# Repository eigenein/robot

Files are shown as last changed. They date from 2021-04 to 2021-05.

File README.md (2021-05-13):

Yes, it's yet another hobby robot, like many of those based on Arduino. So, to make it more fun, it features:

- Raspberry Pi Pico instead of an Arduino board
- My own tiny asynchronous event loop (since [CircuitPython doesn't have one](https://learn.adafruit.com/welcome-to-circuitpython/frequently-asked-questions))
- Custom «asynchronous» BNO055 driver
- Multiple asynchronous tasks running «at the same time»
- Simple REPL over Bluetooth
- Schematics & PCB design included

## Parts

- [Raspberry Pi Pico](https://www.raspberrypi.org/products/raspberry-pi-pico/)
- [Adafruit TB6612 Motor Driver Breakout Board](https://learn.adafruit.com/adafruit-tb6612-h-bridge-dc-stepper-motor-driver-breakout)
- JDY-31 Bluetooth Module
- VL53L1X Distance Sensor Breakout
- BNO055 Absolute Orientation IMU Fusion Breakout
- PS2 Wireless Receiver
- Piezo Buzzer

## Schematics

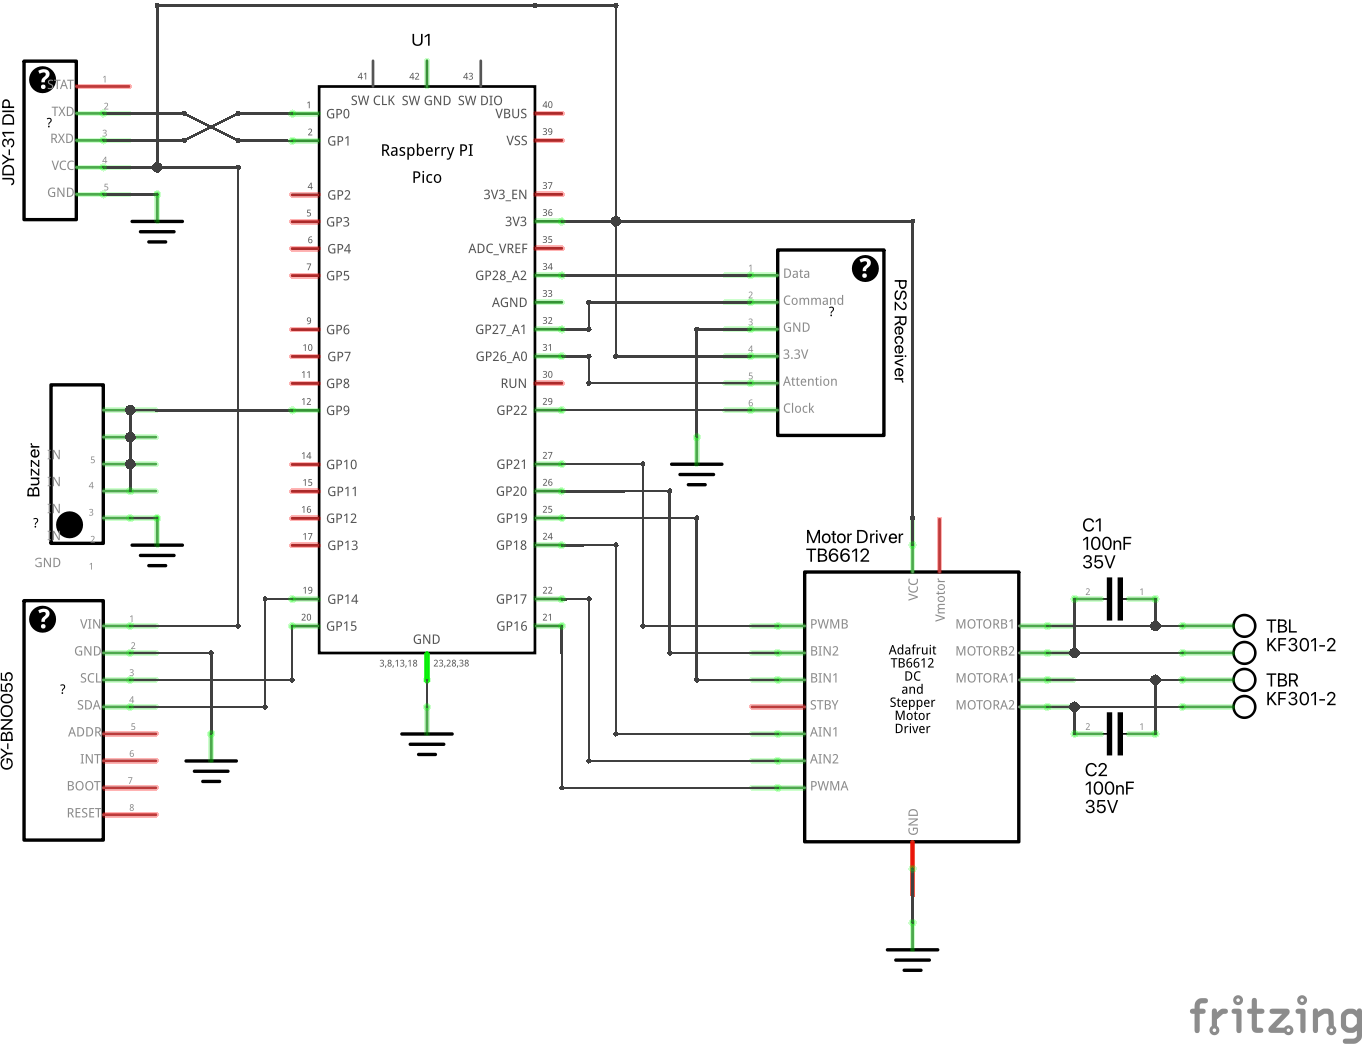
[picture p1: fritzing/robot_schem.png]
Schematics image


## External resources

- [CircuitPython builds](https://adafruit-circuit-python.s3.amazonaws.com/index.html?prefix=bin/raspberry_pi_pico/en_GB/)
- [Pi Pico pinout](https://datasheets.raspberrypi.org/pico/Pico-R3-A4-Pinout.pdf)
- [Material – Color – Dark theme](https://material.io/design/color/dark-theme.html)

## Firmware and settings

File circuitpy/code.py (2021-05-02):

from ulab.numpy import ndarray

from micro_asyncio import event_loop, sleep
from micro_logging import error, info
from peripherals import led, orientation_sensor
from repl import run as run_repl


class Main:
    def __init__(self):
        self._euler = ndarray((0.0, 0.0, 0.0))  # FIXME: make it `None`.

    async def run(self):
        await orientation_sensor.begin()
        event_loop.schedule(
            self._run_telemetry(),
            self._run_orientation_sensor(),
            run_repl(),
        )

    async def _run_telemetry(self):
        """Continuously print telemetry to the console."""
        while True:
            info(" | ".join((
                f"Orientation: {self._euler[0]}",
            )))
            led.value = not led.value
            await sleep(0.5)

    async def _run_orientation_sensor(self):
        """Continuously read the orientation sensor."""
        while True:
            await sleep(0.01)  # fusion output rate is 100Hz
            try:
                self._euler = await orientation_sensor.get_euler()
            except OSError as e:
                error(f"orientation sensor error: {e}")


if __name__ == "__main__":
    info("Starting…")
    event_loop.schedule(Main().run()).run_until_complete()

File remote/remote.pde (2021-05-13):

final color COLOR_BACKGROUND = #121212;
final color COLOR_WHITE = #FFFFFF;

final float TEXT_ALPHA_HIGH_EMPHASIS = 221.85;
final float TEXT_ALPHA_MEDIUM_EMPHASIS = 153;
final float TEXT_ALPHA_DISABLED = 96.9;

final float FONT_SIZE_BODY_1 = 16;
final float FONT_SIZE_BODY_2 = 14;
final float FONT_SIZE_CAPTION = 12;

PFont roboto;

void setup() {
  size(640, 480);
  surface.setTitle("Robot Remote");
  
  smooth();
  noStroke();
  
  roboto = createFont("Roboto", 16, false);
  textFont(roboto);
}

void draw() {
  background(COLOR_BACKGROUND);
  textSize(FONT_SIZE_BODY_1);
  fill(COLOR_WHITE, TEXT_ALPHA_HIGH_EMPHASIS);
  text("Hello, world!", 20, 20);
}

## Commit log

2021-02-24 🎉 Initial commit
    [robot.fz]
2021-02-24 🚧 Add draft schematics
    [robot.fz, robot.fzz]
2021-02-24 🚧 PCB in progress
    [robot.fzz]
2021-02-24 🐛 Fix incorrect connections
    [robot.fzz]
2021-02-24 🐛 Fix Nano Every internal connections
    [robot.fzz]
2021-02-24 🚧 Add Gerber
    [robot_contour.gm1, robot_copperBottom.gbl, robot_copperTop.gtl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]
2021-02-24 🎨 Improve motor driver routing
    [robot.fzz]
2021-02-24 🎨 Improve the component locations
    [robot.fzz]
2021-02-25 🎨 Improve PCB layout
    [robot.fzz]
2021-02-25 ✨ Add PS2 receiver
    [robot.fzz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]
2021-02-25 ✨ Add planned features
2021-02-26 ✨ Add JDY-31 Bluetooth module
    [robot.fzz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]
2021-02-26 ✏️ Update the schematics
2021-02-26 ⚗ Playing with HMC5883L magnetic field sensor
    [robot.fzz]
2021-02-27 ✨ Implement basic compass
2021-02-27 🐛 Fix the capacitors packaging
    [robot.fzz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]
2021-02-27 ✨ Read wheel rotary encoders
2021-02-27 🐛 Fix the buzzer pinout
    [robot.fzz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]
2021-02-27 🚧 Add individual interrupt handlers for both wheels
2021-02-28 🐛 Fix the silk layer, add spare mounting holes
    [robot.fzz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]
2021-02-28 ✨ Implement the draft console functionality
2021-02-28 🚧 Control motors
2021-02-28 ✨ Add extension ports
    [robot.fzz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]
2021-02-28 🐛 Fix README
2021-03-01 💥 Replace HMC5883L with GY-BNO055
    [robot.fzz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]
2021-03-01 📝 Add notes for future development
2021-03-01 🎨 Rename the motor pins according to the schematics
2021-03-01 ✏️ Fix typo
2021-03-01 🎨 Rename `telemetryTicker`
2021-03-01 🎨 Re-position JDY-31 a bit
    [robot.fzz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]
2021-04-01 💥 Integrate BNO055 absolute position sensor
2021-04-01 ✏️ Rename the position sensor to orientation sensor
2021-04-02 ✨ Add PID controller (draft)
2021-04-04 ⚗ Playing around with the PID-controller
    …but gonna remove it in the next iteration
2021-04-05 🔥 Remove the PID controller code
2021-04-05 ♻️ Extract pin manipulation to a separate class
2021-04-05 ♻️ Extract pin manipulation to the `Pin` class
2021-04-05 👷 Add GitHub action
2021-04-05 ✨ Implement the rotary encoders
    This includes removal of the encoder capacitors. Apparently, they were rather harmful. Debouncing is now implemented in the software.
    [robot.fzz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]
2021-04-05 ♻️ Add the `Buzzer` class
2021-04-05 ⚗ Experimenting with position tracking
2021-04-21 Fix Nano Every model, remove R4, remove rotary encoders
    [robot.fzz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]
2021-04-23 💥 Re-design the schematics and PCB for Raspberry Pi Pico
    [robot.fzz]
2021-04-23 📝 No rotary encoders anymore
2021-04-23 🐛 Allow more space for the Pico USB cable
    [robot.fzz]
2021-04-24 💥 Update the schematics image
    [robot.fzz]
2021-04-24 💥 Drop the old README
2021-04-24 📝 Add the parts list
2021-04-24 ♻️ Refactor .gitignore
2021-04-24 🎉 Start the CircuitPython project
2021-04-24 🚧 Controller in progress
    [robot.fzz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]
2021-04-24 🔥 Remove the PlatformIO-based controller for Nano Every
2021-04-24 🚧 Working on the sonar sensor
    [robot.fzz]
2021-04-24 🔥 Remove Gerber files
    Because it's difficult to always keep them up-to-date.
    [robot_PCB1_57680_contour.gm1, robot_PCB1_57680_copperBottom.gbl, robot_PCB1_57680_copperTop.gtl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]
2021-04-24 📝 Sync the schematics
2021-04-24 📝 Sync the Fritzing
    [robot.fzz]
2021-04-24 🐛 Fix the schematics for the Echo signal
    [robot.fzz]
2021-04-25 ♻️ Simplify `Makefile`
2021-04-25 🚧 Testing HC-SR04
2021-04-26 ♻️ Refactor everything into `code.py`, add workaround for HC-SR04
    [code.py]
2021-04-26 ⚗️ Experimenting with HC-SR04
2021-04-26 🔊 Prettier logging
2021-04-26 ✨ Added async event loop
2021-04-27 🔥 Replace `adafruit_logging` with the custom implementation
    [code.py, event_loop.py]
2021-04-27 ✨ Integrate the asynchronous HC-SR04 driver
2021-04-27 🚨 Add stubs missing from CircuitPython
2021-04-27 📦️ Add the Adafruit library bindle
2021-04-27 🔥 Delete the HC-SR04 driver, closes #1
2021-04-27 🔥 Remove the HC-SR04 sensor, closes #1
    [robot.fzz]
2021-04-28 ♻️ Even smaller event loop
2021-04-28 ✨ Start the I²C and BNO055 drivers #4
2021-04-28 ♻️ Rename `io` to `bus` everywhere
2021-04-28 🚧 Developing BNO055 driver #4
2021-04-28 ✨ Implement `Bno055.get_euler`
2021-04-28 ♻️ Simplify the code with `namedtuple`
2021-04-28 ✨ Move orientation sensor readings to a separate coroutine #4
2021-04-28 💡 Add TODOs and FIXMEs
    [micro_asyncio.py, micro_logging.py]
2021-04-29 ♻️ Optimise the event loop
2021-04-29 ♻️ Remove the star import
2021-04-29 💡 Remove TODOs
2021-04-30 ⚡️ Print less through the UART
2021-04-30 ⚡️ Use `micropython.const`
2021-04-30 ⚡️ Drop logging via UART
2021-04-30 🚧 Remote REPL in progress
2021-05-01 📝 Add external resource links
2021-05-02 ✨ Simple remote REPL is ready for use
2021-05-13 🚧 Developing UI in Processing
